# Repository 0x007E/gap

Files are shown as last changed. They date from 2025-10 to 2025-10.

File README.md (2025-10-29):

    

# `GAP` - GamePad (HTLboy)



The `GAP` project is based on a pcb with an [ATmega3208/ATmega4808](#additional-information) and is extended with two [Matrix LED Displays](https://github.com/0x007e/mad). It can be used as controller for games and graphical things. The `GAP` has 8 buttons (1 Cross `[4]`, A & B `[2]`, Select `[1]` and Start `[1]`), 4 LEDs, a potentiometer to control the volume and a built in `UPDI` programmer for the pad itself and the connected displays. Data for displays is sent over `SPI`. The `GAP` also implements a battery controller for [LiPo Batteries](#additional-information). They can be charged over USB. The battery can drive the system for about ~5 hours. There is also a `TWI` interface to load games from an `EEPROM` into the system.

| Experience | Level |
|:---|:-----:|
| Soldering | ?% |
| Mechanical  | ?% |
| Software | ?% |

# Downloads

| Type | File | Description |
|:---:|:---:|:---|
| Schematic | [pdf](https://github.com/0x007E/gap/releases/latest/download/schematic.pdf) / [cadlab](https://cadlab.io/project/29666/main/files) | Schematic files |
| Board | [pdf](https://github.com/0x007E/gap/releases/latest/download/pcb.pdf) / [cadlab](https://cadlab.io/project/29666/main/files) | Board file |
| Drill | [pdf](https://github.com/0x007E/gap/releases/latest/download/drill.pdf) | Drill file |
| PCB | [zip](https://github.com/0x007E/gap/releases/latest/download/kicad.zip) / [tar](https://github.com/0x007E/gap/releases/latest/download/kicad.tar.gz) | KiCAD/Gerber/BoM/Drill files |
| Mechanical | [zip](https://github.com/0x007E/gap/releases/latest/download/freecad.zip) / [tar](https://github.com/0x007E/gap/releases/latest/download/freecad.tar.gz) | FreeCAD/Housing and PCB (STEP) files |
| Display Firmware | [zip](https://github.com/0x007E/mad/releases/latest/download/firmware.zip) / [tar](https://github.com/0x007E/mad/releases/latest/download/firmware.tar.gz) | Firmware for ATtiny406/ATtiny1606 (Display) |
| Demo Firmware | [zip](https://github.com/0x007E/gap/releases/latest/download/firmware-demo.zip) / [tar](https://github.com/0x007E/gap/releases/latest/download/firmware-demo.tar.gz) | Test application for ATmega3208/ATmega4808 |

# Hardware

There are two parts of the hardware. The pcb (`GAP` + 2x`MAD`) and the housing. The pcb is created with [KiCAD](#additional-information) and the housing with `FreeCAD`. The software is programmed with [Microchip (Atmel) Studio](#additional-information). All files are built with `github actions` so that they are ready for a production environment. The housing is printed with a 3D-printer (`Dremel 3D40`).

## PCB

The circuit board is populated on both sides (Top, Bottom). The best way for soldering the `SMD` components is within a vapor phase soldering system and for the `THT` components with a standard soldering system.

### Top Layer

Top Layer

### Bottom Layer

Bottom Layer

## Mechanical

The housing has a tolerance of `0.2mm` on each side of the case. So the pcb should fit perfectly in the housing. The tolerance can be modified with `FreeCAD` in the `Parameter` Spreadsheet.

### Assembled

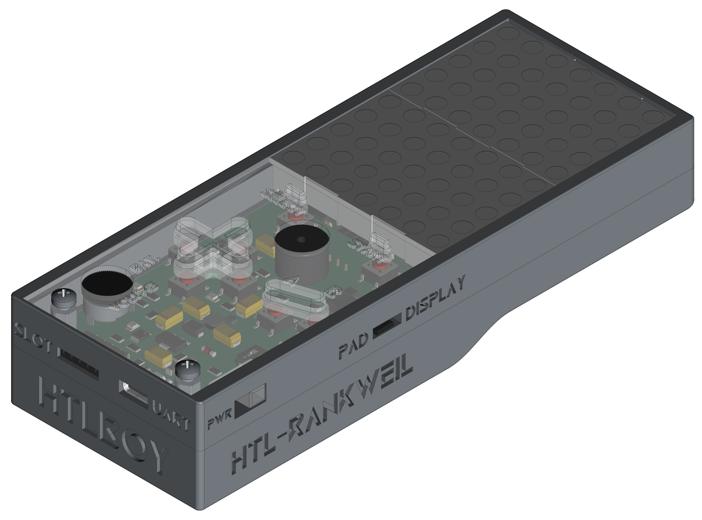
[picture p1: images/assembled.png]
Assembled


#### Exploded

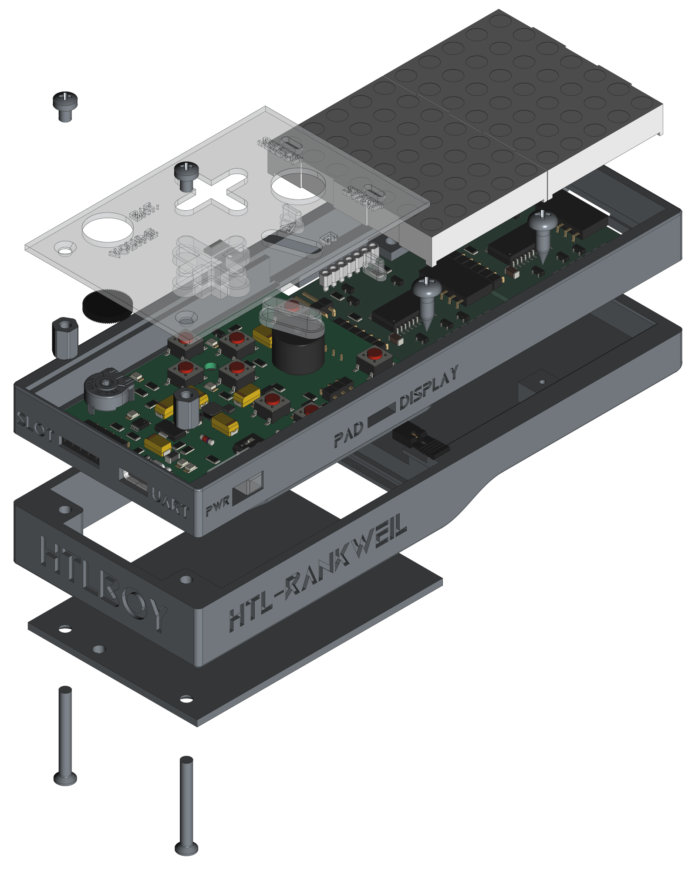
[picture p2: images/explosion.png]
Exploded


# Programming/Setup

For programming the `GAP` is necessary to power the system with `5V` over the USB jack. The `GAP` has an integrated `UPDI` programmer and a pin to select the programming device (`Pad` or `Display`). With Jumper `J3/J4` bridged the [UPDI](#additional-information) programmer is enabled. To program the `Pad` it is necessary to set the Jumper `JP2` between the pins `2-3`. If jumper `JP2` is set between `1-2` the `MAD` display(s) can be programmed (set the jumper `JP1` at the display that should be programmed). The firmware for the `pad`/`display` can be downloaded (see the [download section](#downloads)).

``` bash
#              +---+---+---+---+---+---+  
#          +---+ 1 | 2 | 3 | 4 | 5 | 6 +---+
#          |   +---+---+---+---+---+---+ D |
#          |             S               I |
#          |         U   O               S |
#          |     V   P       S       G   P |
#          |     C   D       C   S   N   L |
#          |     C   I       K   S   D   A |
#        +-+---+         S               Y |
# (*) -> | JP1 |         I                 |
#        +-+---+---+---+---+---+---+---+ 2 |
#          +---+ 1 | 2 | 3 | 4 | 5 | 6 +---+
#              +-+-+-+-+-+-+-+-+-+-+-+-+
#                |   |   |   |   |   |
#              +-+-+-+-+-+-+-+-+-+-+-+-+ 
#          +---+ 1 | 2 | 3 | 4 | 5 | 6 +---+
#          |   +---+---+---+---+---+---+ D |
#          |             S               I |
#          |         U   O               S |
#          |     V   P       S       G   P |
#          |     C   D       C   S   N   L |
#          |     C   I       K   S   D   A |
#        +-+---+         S               Y |
# (*) -> | JP1 |         I                 |
#        +-+---+---+---+---+---+---+---+ 1 |
#          +---+ 1 | 2 | 3 | 4 | 5 | 6 +---+
#              +-+-+-+-+-+-+-+-+-+-+-+-+
#                |   |   |   |   |   |
#              +-+-+-+-+-+-+-+-+-+-+-+-+ 
#          +---+ 1 | 2 | 3 | 4 | 5 | 6 +---+
#          |   +---+---+---+---+---+---+   |
#          |     V   U   M   S   S         |
#          |     C   P   O   C   S         |
#          |     C   D       K             |
#          |         I                  +--+-+
#          |                            |  J +       ---+ Program selected (*) MAD
#          |      G                     |  P +---+   ---+
#          |      A                     |  1 +---+ Program GAP
#          |      M                     +--+-+
#          |      E                        |
#          |      P                        |
#          |      A            SW 11       |
#          |      D        U +---+---+     |
#          |               P | X | X |     |
#          |               D | X | X |     |
#          |               I |   |   |     |
#          |                 +---+---+     |
#          |                     +---+     |
#          | +-------+           | U |     |
#          +-+  TWI  +-----------+ S +-----+
#            +-+++++-+           | B |
#                                +-+-+
#                                  |
#                                  |
#                    +-------------+---------+
#                    |                       |
#                    | +-------------------+ |
#                    | | AVR-Dude/TeraTerm | |
#                    | | ~~~~~~~~          | |
#                    | | ~~~~~             | |
#                    | | ~~~~~~~~~~~~      | |
#                    | |                   | |
#                    | +-------------------+ |
#                    |                       |
#                    | Computer              |
#                    |                       |
#                    +-----------------------+
```

## FUSES

| Register  | Value  |
|:---:|:---:|
| `APPEND`  | `0x00` |
| `BODCFG`  | `0x00` |
| `BOOTEND` | `0x00` |
| `OSCCFG`  | `0x02` |
| `SYSCFG0` | `0xCC` |
| `SYSCFG1` | `0x00` |
| `WDTCFG`  | `0x00` |

> It is necessary to press the reset button during `avr-dude` is running! Otherwise the `UPDI` programming does not work. Remove Jumper `J3`/`J4` after programming.

## Commands

### Gamepad

``` bash
# With ATmega3208                              !PORT
avrdude.exe -c serialupdi -p m3208 -b 57600 -P COM? -U flash:w:"/path/to/file.hex":a -U eeprom:w:"/path/to/file.eep":a -v

# With ATmega4808                              !PORT
avrdude.exe -c serialupdi -p m4808 -b 57600 -P COM? -U flash:w:"/path/to/file.hex":a -U eeprom:w:"/path/to/file.eep":a -v
```

### Display

``` bash
# With ATtiny406                              !PORT
avrdude.exe -c serialupdi -p t406 -b 57600 -P COM? -U flash:w:"/path/to/file.hex":a -U eeprom:w:"/path/to/file.eep":a -v

# With ATtiny1606                              !PORT
avrdude.exe -c serialupdi -p t1606 -b 57600 -P COM? -U flash:w:"/path/to/file.hex":a -U eeprom:w:"/path/to/file.eep":a -v
```

# Software

The gamepad can be controlled with different libraries to read the input, set the output and control the data on display. An overview of the interfaces are displayed in the [dataflow](#dataflow-diagram) diagram. There is a demo software that is using the libraries to setup and control the gamepad and display (`GAP_LIB`) and a simple game (`GAP_GAME`).

## Dataflow diagram

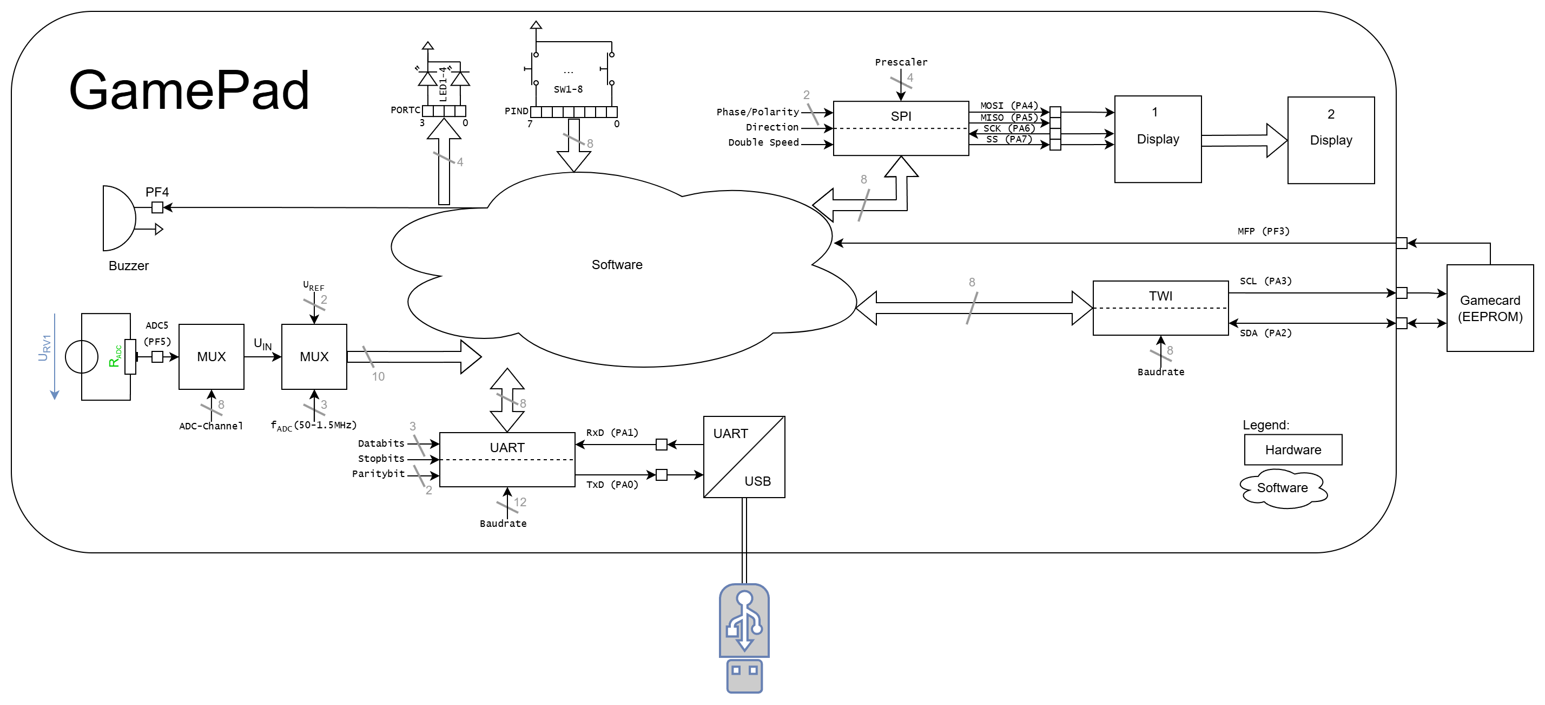
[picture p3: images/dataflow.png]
Dataflow


### Example Library (`matrix.h`)

With the attached demo library (`MAD_LIB`) it is quiet easy to use the display. To setup the matrix display library some `defines` needs to be adjusted.

``` c
// Setup the number of displays that are cascaded in matrix.h
#ifndef MATRIX_DISPLAYS
    #define MATRIX_DISPLAYS 2
#endif
```

``` c
#include "../lib/matrix/matrix.h"

int main(void)
{
    matrix_init();
    matrix_reset();
    _delay_ms(MATRIX_RESET_RECOVERY_TIME_MS);
    matrix_enable();

    matrix_char(1, 'A');
    _delay_ms(1000);
    matrix_char(2, 'B');

    matrix_frame(buffer);
    // ...
}
```

# Additional Information

| Type | Link | Description |
|:---:|:---:|:---|
| ATtiny406  | [pdf](https://ww1.microchip.com/downloads/en/DeviceDoc/Microchip%208bit%20mcu%20AVR%20ATtiny406%20data%20sheet%2040001976A.pdf) | ATtiny microcontroller |
| ATtiny1606 | [pdf](http://ww1.microchip.com/downloads/en/DeviceDoc/ATtiny806_1606_Data_Sheet_40002029A.pdf) | ATtiny microcontroller |
| ATmega3208 | [pdf](https://ww1.microchip.com/downloads/en/DeviceDoc/ATmega3208-3209-Data-Sheet-DS40002174A.pdf) | Microchip ATmega Datasheet |
| ATmega4808 | [pdf](https://ww1.microchip.com/downloads/en/DeviceDoc/ATmega4808-4809-Data-Sheet-DS40002173A.pdf) | Microchip ATmega Datasheet |
| TA20-11SRWA | [pdf](https://www.kingbrightusa.com/images/catalog/spec/ta20-11srwa.pdf) | Dot Matrix Dispaly |
| Atmel ICE | [pdf](https://ww1.microchip.com/downloads/en/DeviceDoc/Atmel-ICE_UserGuide.pdf) | Atmel ICE datasheet |
| UPDI | [web](https://github.com/0x007e/updi) | UPDI-Adapter with AVR-Dude |
| Microchip Studio | [web](https://www.microchip.com/en-us/tools-resources/develop/microchip-studio) | Download page for Microchip Studio |
| KiCAD | [web](https://www.kicad.org/) | KiCAD project page |
| FreeCAD | [web](https://www.freecad.org/) | FreeCAD project page |
| TeraTerm | [web](https://github.com/TeraTermProject/teraterm/releases/download/v5.3/teraterm-5.3.zip) | Terminal software for UART |

---

R. GAECHTER

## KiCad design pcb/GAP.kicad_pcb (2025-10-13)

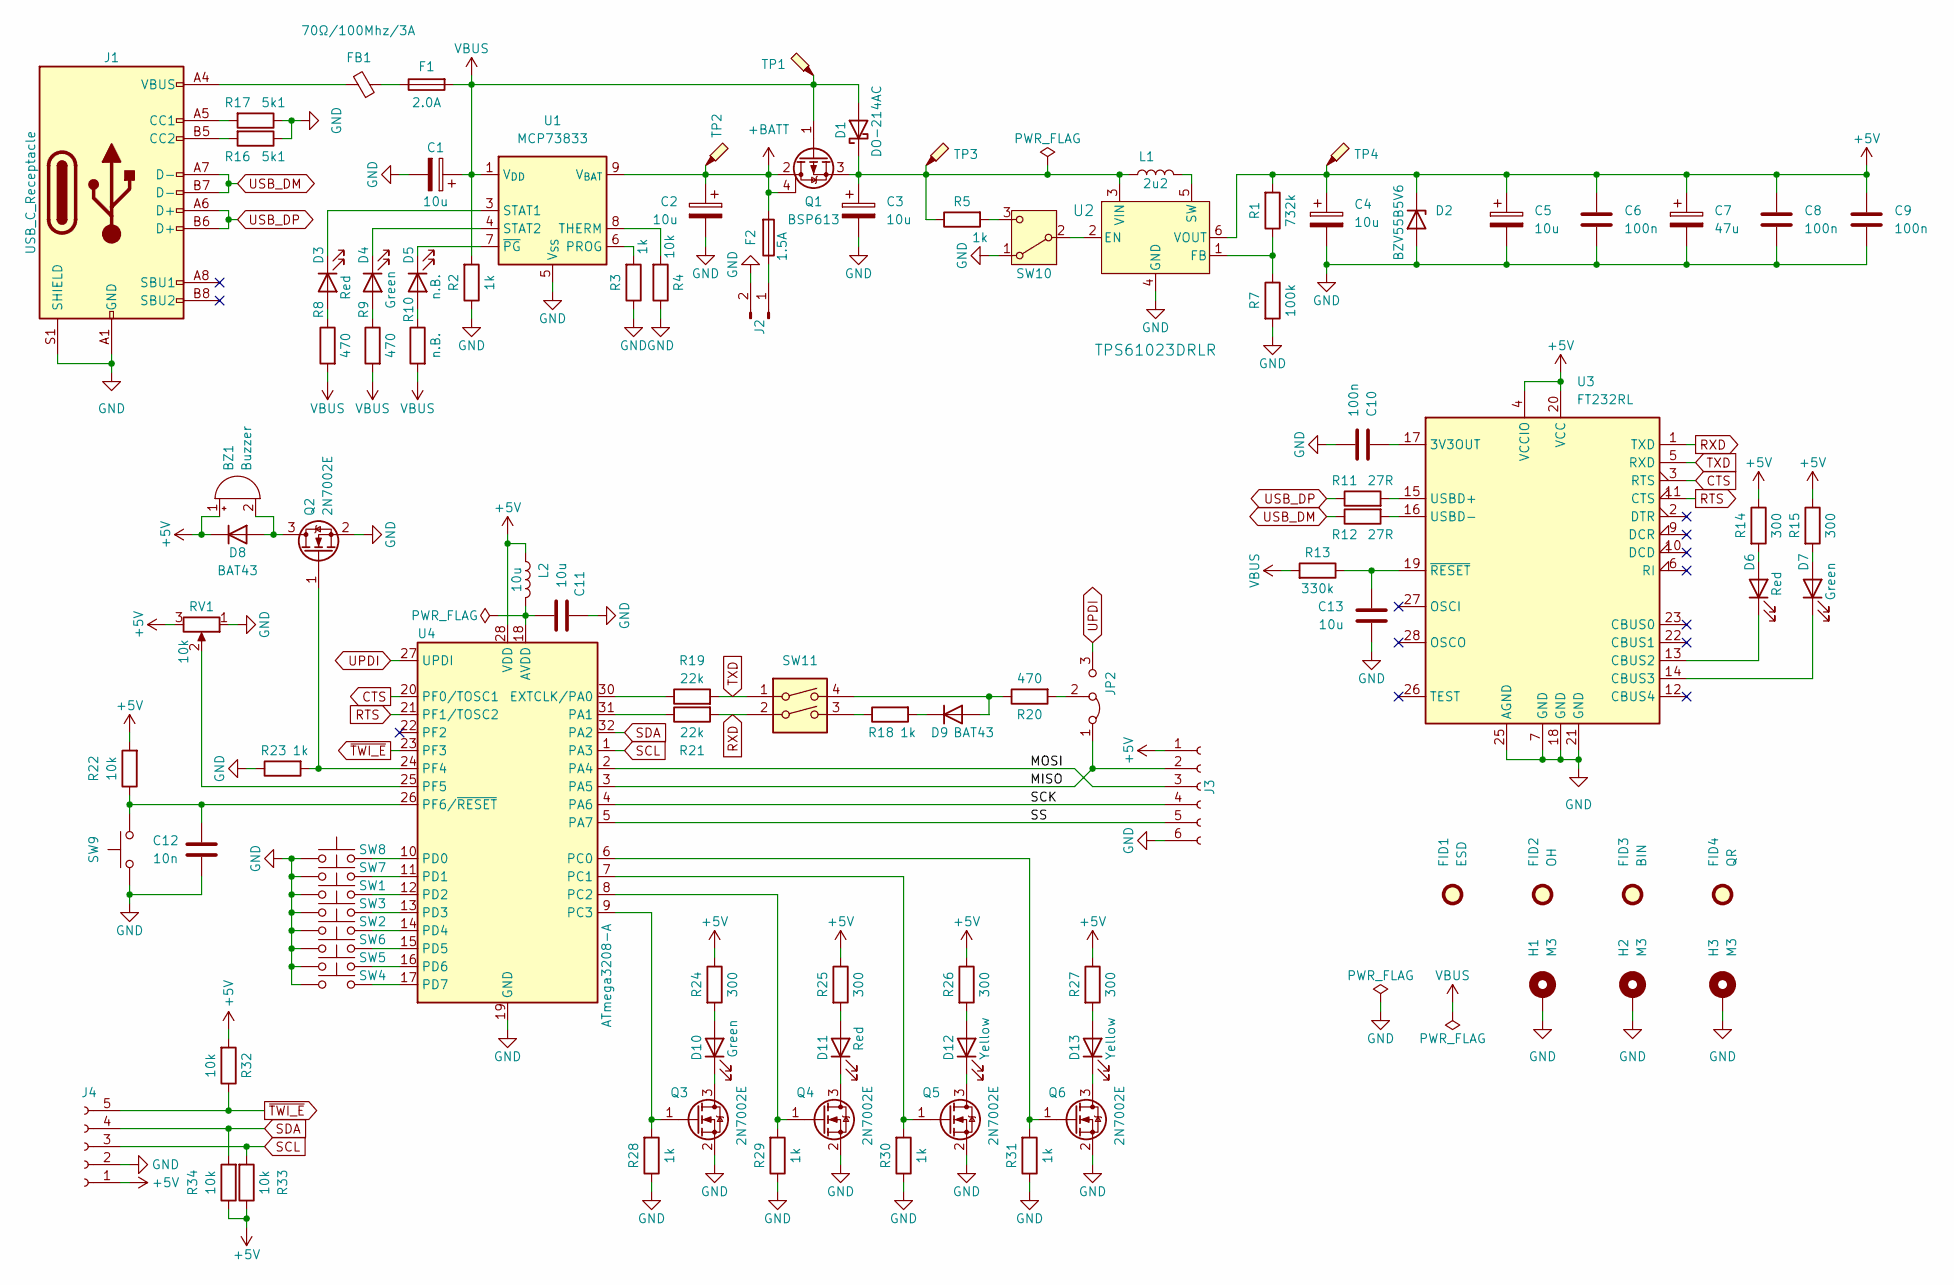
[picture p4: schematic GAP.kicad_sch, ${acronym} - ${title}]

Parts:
BZ1: Buzzer; MagneticBuzzer_ProSignal_ABT-410-RC
C1, C2, C3, C4, C5: 10u; CP_EIA-6032-28_Kemet-C
C6, C8, C9, C10: 100n; C_1206_3216Metric
C7: 47u; CP_EIA-6032-28_Kemet-C
C11, C13: 10u; C_1206_3216Metric
C12: 10n; C_1206_3216Metric
D1: DO-214AC; D_SMA
D2: BZV55B5V6; D_MiniMELF
D3, D6, D11: Red; LED_1206_3216Metric
D4, D7, D10: Green; LED_1206_3216Metric
D5: n.B.; LED_1206_3216Metric
D8, D9: BAT43; D_MiniMELF
D12, D13: Yellow; LED_1206_3216Metric
F1: 2.0A; Fuse_1206_3216Metric
F2: 1.5A; Fuse_1206_3216Metric
FB1: 70Ω/100Mhz/3A; L_1206_3216Metric
FID1: ESD; ESD-Logo_6.6x6mm_SilkScreen
FID2: OH; OSHW-Logo_5.7x6mm_SilkScreen
FID3: BIN; WEEE-Logo_4.2x6mm_SilkScreen
FID4: QR; QR_0x007e
H1, H2, H3: M3; MountingHole_3.2mm_M3_DIN965_Pad
J1: USB_C_Receptacle; USB_C_Receptacle_GCT_USB4110
J2: Conn_01x02_Pin; JST_PH_S2B-PH-K_1x02_P2.00mm_Horizontal
J3: Conn_01x06_Socket; PinSocket_1x06_P2.54mm_Horizontal
J4: Conn_01x05_Socket; PinSocket_1x05_P2.54mm_Horizontal
JP2: Jumper_3_Bridged12; PinHeader_1x03_P2.54mm_Horizontal
L1: 2u2; L_Vishay_IFSC-1515AH_4x4x1.8mm
L2: 10u; L_1206_3216Metric
Q1: BSP613; SOT-223
Q2, Q3, Q4, Q5, Q6: 2N7002E; SOT-23
R1: 732k; R_1206_3216Metric
R2, R3, R5, R18, R23, R28, R29, R30, R31: 1k; R_1206_3216Metric
R4, R22, R32, R33, R34: 10k; R_1206_3216Metric
R7: 100k; R_1206_3216Metric
R8, R9, R20: 470; R_1206_3216Metric
R10: n.B.; R_1206_3216Metric
R11, R12: 27R; R_1206_3216Metric
R13: 330k; R_1206_3216Metric
R14, R15, R24, R25, R26, R27: 300; R_1206_3216Metric
R16, R17: 5k1; R_1206_3216Metric
R19, R21: 22k; R_1206_3216Metric
RV1: 10k; Potentiometer_Piher_PT-10-V10_Vertical
SW1, SW2, SW3, SW4, SW5, SW6, SW7, SW8, SW9: SW_Push; SW_SPST_PTS645
SW10: SW_SPDT; SW_SPDT_CK_JS102011SAQN
SW11: SW_DIP_x02; SW_DIP_SPSTx02_Slide_6.7x6.64mm_W8.61mm_P2.54mm_LowProfile
TP1, TP2, TP3, TP4: TestPoint_Probe; TestPoint_Pad_D1.0mm
U1: MCP73833; MSOP-10_3x3mm_P0.5mm
U2: TPS61023DRLR; SOT-563
U3: FT232RL; SSOP-28_5.3x10.2mm_P0.65mm
U4: ATmega3208-A; TQFP-32_7x7mm_P0.8mm

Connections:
+5V: BZ1.1 (+), C4.1, C5.1, C6.1, C7.1, C8.1, C9.1, D2.1 (K), D8.1 (K), J3.1, J4.1, L2.1, R1.2, R14.1, R15.1, R22.2, R24.1, R25.1, R26.1, R27.1, R32.2, R33.1, R34.1, RV1.3, TP4.1, U2.6 (VOUT), U3.4 (VCCIO), U3.20 (VCC), U4.28 (VDD)
+BATT: C2.1, F2.2, Q1.2 (D), Q1.4 (D), TP2.1, U1.9 (V_{BAT}), U1.10 (V_{BAT})
/MISO: J3.2, JP2.1 (A), U4.3 (PA5)
/MOSI: J3.3, U4.2 (PA4)
/SCK: J3.4, U4.4 (PA6)
/SS: J3.5, U4.5 (PA7)
CTS: U3.3 (RTS), U4.20 (PF0/TOSC1)
GND: C1.2, C2.2, C3.2, C4.2, C5.2, C6.2, C7.2, C8.2, C9.2, C10.1, C11.2, C12.2, C13.1, D2.2 (A), H1.1, H2.1, H3.1, J1.A1 (GND), J1.A12 (GND), J1.B1 (GND), J1.B12 (GND), J1.S1 (SHIELD), J2.2, J3.6, J4.2, Q2.2 (S), Q3.2 (S), Q4.2 (S), Q5.2 (S), Q6.2 (S), R2.1, R3.1, R4.1, R7.2, R16.1, R17.1, R23.1, R28.1, R29.1, R30.1, R31.1, RV1.1, SW1.2, SW2.1, SW3.1, SW4.2, SW5.1, SW6.1, SW7.1, SW8.2, SW9.1, SW10.1 (A), U1.5 (V_{SS}), U2.4 (GND), U3.7 (GND), U3.18 (GND), U3.21 (GND), U3.25 (AGND), U4.19 (GND), U4.29 (GND)
unnamed: BZ1.2 (-), D8.2 (A), Q2.3 (D)
unnamed: C3.1, D1.1 (K), L1.1, Q1.3 (S), R5.1, TP3.1, U2.3 (VIN)
unnamed: D3.2 (A), R8.1
unnamed: D3.1 (K), U1.3 (STAT1)
unnamed: D4.2 (A), R9.1
unnamed: D4.1 (K), U1.4 (STAT2)
unnamed: D5.2 (A), R10.1
unnamed: D5.1 (K), U1.7 (~PG)
unnamed: D6.2 (A), R14.2
unnamed: D6.1 (K), U3.13 (CBUS2)
unnamed: D7.2 (A), R15.2
unnamed: D7.1 (K), U3.14 (CBUS3)
unnamed: D9.2 (A), R20.1, SW11.4
unnamed: D9.1 (K), R18.2
unnamed: D10.2 (A), R24.2
unnamed: D10.1 (K), Q3.3 (D)
unnamed: D11.2 (A), R25.2
unnamed: D11.1 (K), Q4.3 (D)
unnamed: D12.2 (A), R26.2
unnamed: D12.1 (K), Q5.3 (D)
unnamed: D13.2 (A), R27.2
unnamed: D13.1 (K), Q6.3 (D)
unnamed: F1.1, FB1.1
unnamed: FB1.2, J1.A4 (VBUS), J1.A9 (VBUS), J1.B4 (VBUS), J1.B9 (VBUS)
unnamed: J1.A5 (CC1), R17.2
unnamed: J1.B5 (CC2), R16.2
unnamed: F2.1, J2.1
unnamed: JP2.2 (C), R20.2
unnamed: Q2.1 (G), R23.2, U4.24 (PF4)
unnamed: Q3.1 (G), R28.2, U4.9 (PC3)
unnamed: Q4.1 (G), R29.2, U4.8 (PC2)
unnamed: Q5.1 (G), R30.2, U4.7 (PC1)
unnamed: Q6.1 (G), R31.2, U4.6 (PC0)
unnamed: R18.1, SW11.3
unnamed: SW10.2 (B), U2.2 (EN)
unnamed: R5.2, SW10.3 (C)
unnamed: R3.2, U1.6 (PROG)
unnamed: R4.2, U1.8 (THERM)
unnamed: R1.1, R7.1, U2.1 (FB)
unnamed: L1.2, U2.5 (SW)
unnamed: C10.2, U3.17 (3V3OUT)
unnamed: R11.2, U3.15 (USBD+)
unnamed: R12.2, U3.16 (USBD-)
unnamed: C13.2, R13.1, U3.19 (~RESET)
unnamed: C11.1, L2.2, U4.18 (AVDD)
unnamed: R19.1, U4.30 (EXTCLK/PA0)
unnamed: R21.1, U4.31 (PA1)
unnamed: SW8.1, U4.10 (PD0)
unnamed: SW7.2, U4.11 (PD1)
unnamed: SW1.1, U4.12 (PD2)
unnamed: SW3.2, U4.13 (PD3)
unnamed: SW2.2, U4.14 (PD4)
unnamed: SW6.2, U4.15 (PD5)
unnamed: SW5.2, U4.16 (PD6)
unnamed: SW4.1, U4.17 (PD7)
unnamed: RV1.2, U4.25 (PF5)
unnamed: C12.1, R22.1, SW9.2, U4.26 (PF6/~RESET)
RTS: U3.11 (CTS), U4.21 (PF1/TOSC2)
RXD: R21.2, SW11.2, U3.1 (TXD)
SCL: J4.3, R33.2, U4.1 (PA3)
SDA: J4.4, R34.2, U4.32 (PA2)
TXD: R19.2, SW11.1, U3.5 (RXD)
UPDI: JP2.3 (B), U4.27 (UPDI)
USB_DM: J1.A7 (D-), J1.B7 (D-), R12.1
USB_DP: J1.A6 (D+), J1.B6 (D+), R11.1
VBUS: C1.1, D1.2 (A), F1.2, Q1.1 (G), R2.2, R8.2, R9.2, R10.2, R13.2, TP1.1, U1.1 (V_{DD}), U1.2 (V_{DD})
~TWI_E: J4.5, R32.1, U4.23 (PF3)

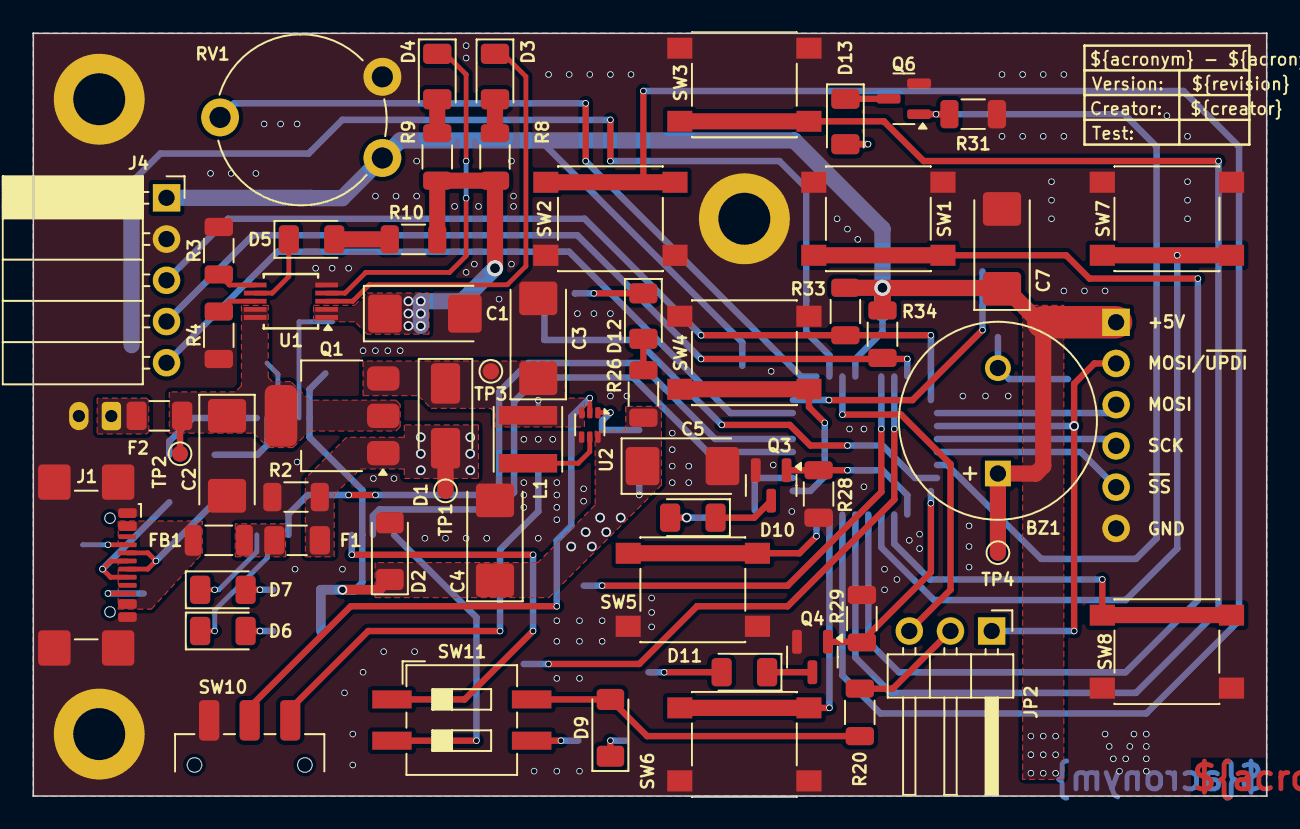
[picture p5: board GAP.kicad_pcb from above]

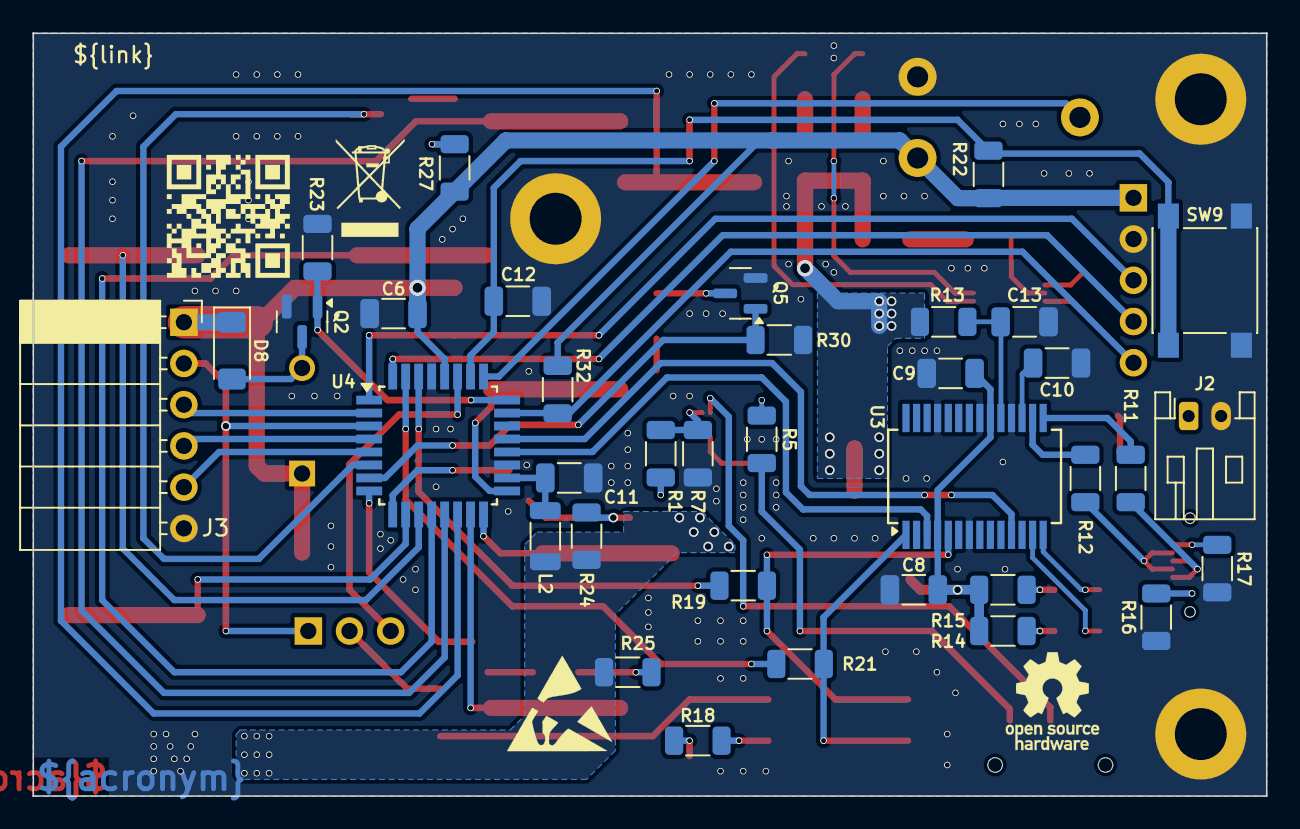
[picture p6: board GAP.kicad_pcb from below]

Board: 2 copper layers, 76.0 x 47.0 mm, 103 parts (40 on the bottom side), 75 nets.

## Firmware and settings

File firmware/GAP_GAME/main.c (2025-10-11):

#include "main.h"


unsigned char buffer[(MATRIX_DISPLAYS * MATRIX_ROWS)];

int main(void)
{
	system_init();
	control_init();

    matrix_init();
    matrix_reset();
    _delay_ms(MATRIX_RESET_RECOVERY_TIME_MS);
    matrix_enable();

    uart_init();
	
	unsigned char x_pos = (MATRIX_ROWS / 2), y_pos = (MATRIX_DISPLAYS * MATRIX_COLUMNS / 2);
	unsigned char new_dot = 1, dot_x_pos, dot_y_pos;

	TCA0.SINGLE.CTRLA = TCA_SINGLE_CLKSEL_2_bm | TCA_SINGLE_ENABLE_bm;
	TCB0.CTRLA = TCB_CLKSEL_1_bm | TCB_ENABLE_bm; 

	while (1)
	{
		// Create a new dot position
		if(new_dot)
		{
			do
			{
				dot_x_pos = TCA0.SINGLE.CNT%(MATRIX_ROWS);
				dot_y_pos = TCB0.CNT%(MATRIX_DISPLAYS * MATRIX_COLUMNS);

			} while ((dot_x_pos == x_pos) || (dot_y_pos == y_pos) || (dot_x_pos == y_pos) || (dot_y_pos == x_pos));

			new_dot = 0;
		}

		// Create crosshairs on display
		for (unsigned char i=0; i < sizeof(buffer)/sizeof(buffer[0]); i++)
		{
			buffer[i] = 0x00;

			if((y_pos/MATRIX_COLUMNS) == (i/MATRIX_ROWS))
			{
				buffer[i] = (1<<(y_pos%MATRIX_COLUMNS));
			}

			if(x_pos == (i%MATRIX_ROWS))
			{
				buffer[i] = 0xFF;
			}
		}
		buffer[(dot_x_pos + ((dot_y_pos / MATRIX_COLUMNS) * MATRIX_ROWS))] |= (1<<(dot_y_pos%MATRIX_COLUMNS));

		matrix_frame(buffer);
		printf("POS(x=%1u/y=%1u) | DOT(x=%1u/y=%1u)    \r", x_pos, y_pos, dot_x_pos, dot_y_pos);

		char temp = 0;

		if(uart_scanchar(&temp) == UART_Received)
		{
			
		}

		if(control_status(CTRL_SW_RIGHT) || temp == 'd')
		{
    		control_led(CTRL_LED_CROSS_2, CTRL_MODE_TOGGLE);

			_delay_ms(100);

			if(x_pos < (MATRIX_ROWS - 1))
			{
				x_pos++;
			}
			else
			{
				x_pos = 0;
			}
		}
		if(control_status(CTRL_SW_LEFT) || temp == 'a')
		{
    		control_led(CTRL_LED_CROSS_2, CTRL_MODE_TOGGLE);

			_delay_ms(100);

			if(x_pos > 0)
			{
				x_pos--;
			}
			else
			{
				x_pos = (MATRIX_ROWS - 1);
			}
		}
		if(control_status(CTRL_SW_DOWN)  || temp == 's')
		{
    		control_led(CTRL_LED_CROSS_1, CTRL_MODE_TOGGLE);

			_delay_ms(100);

			if(y_pos > 0)
			{
				y_pos--;
			}
			else
			{
				y_pos = ((MATRIX_DISPLAYS * MATRIX_COLUMNS) - 1);
			}
		}
		if(control_status(CTRL_SW_UP)  || temp == 'w')
		{
    		control_led(CTRL_LED_CROSS_1, CTRL_MODE_TOGGLE);

			_delay_ms(100);

			if(y_pos < ((MATRIX_DISPLAYS * MATRIX_COLUMNS) - 1))
			{
				y_pos++;
			}
			else
			{
				y_pos = 0;
			}
		}
		if(control_status(CTRL_SW_A)  || control_status(CTRL_SW_B)  || temp == 'f')
		{
    		control_led(CTRL_LED_A | CTRL_LED_B, CTRL_MODE_TOGGLE);

			_delay_ms(100);
			
			if((x_pos == dot_x_pos) && (y_pos == dot_y_pos))
			{
				new_dot = 1;
			}
		}
		_delay_ms(10);
	}
}

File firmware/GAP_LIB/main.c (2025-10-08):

#include "main.h"

unsigned char buffer[(MATRIX_DISPLAYS * MATRIX_ROWS)];

int main(void)
{
	system_init();
	
	matrix_init();
	matrix_reset();
	_delay_ms(MATRIX_RESET_RECOVERY_TIME_MS);
	
	adc_init();
	adc_channel(ADC_CH15);
	uart_init();
	
	printf("\n\rGamepad Initializing\n\r");
	
	matrix_enable();

	unsigned char i=1;

	for (unsigned char y=0; y < (MATRIX_DISPLAYS * MATRIX_ROWS); y++)
	{

		for (unsigned char x=0; x < MATRIX_COLUMNS; x++)
		{
			if(i <= x)
			{
				break;
			}
			buffer[y] |= (1<<(i - 1));
		}

		if((++i) > MATRIX_COLUMNS)
		{
			i = 1;
		}
	}
	matrix_frame(buffer);
	_delay_ms(1000);

	while (1)
	{
		printf("ADC-Value(CH15): %4u  \r", (adc_read()));
		
		if(control_status(CTRL_SW_UP))
		{
            control_led(CTRL_LED_CROSS_1, CTRL_MODE_TOGGLE);
            matrix_char(1, 'A');
		}
		if(control_status(CTRL_SW_DOWN))
		{
    		control_led(CTRL_LED_CROSS_1, CTRL_MODE_TOGGLE);
			matrix_char(2, 'B');
		}
		if(control_status(CTRL_SW_LEFT))
		{
    		control_led(CTRL_LED_CROSS_2, CTRL_MODE_TOGGLE);
			matrix_char(1, 'C');
		}
		if(control_status(CTRL_SW_RIGHT))
		{
    		control_led(CTRL_LED_CROSS_2, CTRL_MODE_TOGGLE);
			matrix_char(2, 'D');
		}
		if(control_status(CTRL_SW_A))
		{
    		control_led(CTRL_LED_A, CTRL_MODE_TOGGLE);
			matrix_char(1, 'E');
		}
		if(control_status(CTRL_SW_B))
		{
    		control_led(CTRL_LED_B, CTRL_MODE_TOGGLE);
			matrix_char(2, 'F');
		}
		if(control_status(CTRL_SW_SELECT))
		{
            control_led(CTRL_LED_CROSS_1 | CTRL_LED_CROSS_1 | CTRL_LED_A | CTRL_LED_B, CTRL_MODE_ON);
			matrix_char(1, 'X');
			matrix_char(2, 'X');
		}
		if(control_status(CTRL_SW_START))
		{
    		control_led(CTRL_LED_CROSS_1 | CTRL_LED_CROSS_1 | CTRL_LED_A | CTRL_LED_B, CTRL_MODE_OFF);
			matrix_clear(1);
			matrix_clear(2);
		}
	}
}

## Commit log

2025-10-08 Add electronical parts
    [GAP.kicad_pcb, GAP.kicad_sch]
2025-10-11 Change SW10 library
    [GAP.kicad_pcb, GAP.kicad_sch]
2025-10-12 Add RTS/CTS to UART interface
    [GAP.kicad_pcb, GAP.kicad_sch]
2025-10-13 Change partlist vendors
    [GAP.kicad_pcb, GAP.kicad_sch]

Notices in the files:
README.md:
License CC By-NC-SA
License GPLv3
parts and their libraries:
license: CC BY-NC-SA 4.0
